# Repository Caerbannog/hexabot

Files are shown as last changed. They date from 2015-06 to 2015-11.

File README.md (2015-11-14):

Hexabot Sources
===============

Design files and source code of a mobile robot for the [Eurobot competition](http://www.eurobot.org/).

The controller board is built in [KiCad](http://www.kicad-pcb.org/)
around a [dsPIC33EP256MU806](https://www.microchip.com/products/dsPIC33EP256MU806) (QFN, motor control, USB).
You can control it from your development machine or an embedded Linux like the Raspberry Pi (raspbian jessie recommended).

Controller PCB
--------------
The board handles various functions: motor control, odometry, sensors and servomotors.
It has two layers, 10cm*10cm and mostly 0806 SMT components.

You can buy 10 PCBs for 32$ at [SeeedStudio](http://www.seeedstudio.com/service/index.php?r=pcb).
Then we hand-soldered ours.

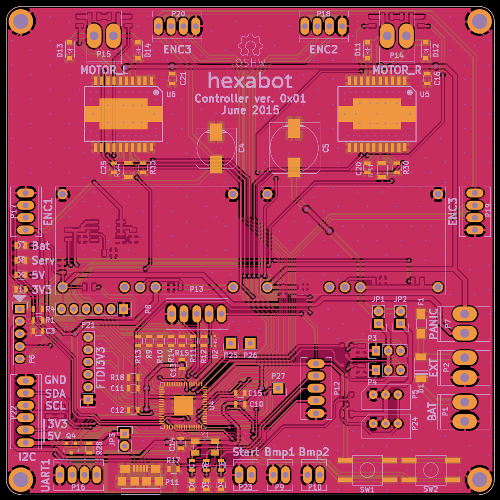
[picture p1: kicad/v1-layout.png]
Layout v1


Embedded Software
-----------------
The source code for the microcontroller is in [hexabot-dsPIC33.X](hexabot-dsPIC33.X/).
It is controlled with the tools in [linux](linux/). Most are Python scripts that
use [PyUSB](https://walac.github.io/pyusb/) to communicate with the board through independant USB endpoints:
- Bulk commands to set parameters and read back values. The basic idea is to run `./command.py <register> <value>` to set a value.
- Bulk metrics broadcasting, isochronous packets for time-sensitive data. Dump them with `./usb_controller.py`.
- Serial port for debugging. Show the debug console with `miniterm.py /dev/ttyACM* 9600 -D`.

A higher level scripts like `joystick.py` uses the command endpoint to let you control the motors with a USB joystick.

User Interface
--------------
The [ui](ui/) directory contains a Python webserver with these features:
- live updates of the position according to odometry,
- graphs to visualize metrics,
- maybe someday a way to send commands.

Setup
-----
Download and install the [MPLABX IDE](http://www.microchip.com/mplabx/) and the [XC16 compiler](http://www.microchip.com/compilers/).
You need xc16 v1.25+ because of bug XC16-781 (snprintf).
Sadly the peripheral libraries were last shipped with v1.24 and the new Code Configurator doesn't support dsPIC33E yet.
You need to copy the libraries from one installed version to the other.

Install Python 3 and debugging tools like Wireshark.
For Ubuntu 15.04 you can run:
```bash
git clone https://github.com/Caerbannog/hexabot.git
sudo apt-get install python3-pip wireshark
sudo pip3 install pyusb==1.0.0b1 autobahn==0.10.4 pyinotify==0.9.6 bottle==0.12.8 pyserial
sudo adduser $USER dialout
sudo adduser $USER wireshark
echo usbmon | sudo tee -a /etc/modules
sudo cp 99-hexabot.rules /etc/udev/rules.d/
sudo service udev reload # then you need to replug the device
```

Contributing
------------
Pull requests are welcome on the project page:
<https://github.com/Caerbannog/hexabot>

Licenses
--------
- Hardware design files are published under the CERN OHL v.1.2.
- Source code is published under the GPLv3 or later.
- Note that Microchip's USB library and the CDC-basic demo have a more restrictive license.

TODO list
---------
- Documentation for the code. Links to documentation for the motor control and odometry.

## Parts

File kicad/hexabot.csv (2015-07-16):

Reference | Value | Footprint | Datasheet
U4 | DSPIC33EP256MU806 | hexabot:QFN-64-1EP_9x9mm_Pitch0.5mm
D4 | LEDR | Resistors_SMD:R_0805
D5 | LEDY | Resistors_SMD:R_0805
D6 | LEDG | Resistors_SMD:R_0805
R19 | 470R | Resistors_SMD:R_0805
R20 | 470R | Resistors_SMD:R_0805
R21 | 470R | Resistors_SMD:R_0805
Y1 | 8M | hexabot:XTAL_5x3.2 | http://www.abracon.com/Resonators/abm3b.pdf
R8 | 1M | Resistors_SMD:R_0805
C7 | 18p | Resistors_SMD:R_0805
C8 | 18p | Resistors_SMD:R_0805
P6 | PICKIT | Pin_Headers:Pin_Header_Straight_1x05
P11 | USB_B | hexabot:MICRO-B_USB
JP3 | JUMPER | Pin_Headers:Pin_Header_Straight_1x02
LOGO1 | OPEN_HARDWARE_1 | Symbols:Symbol_OSHW-Logo_SilkScreen
P13 | NC | Sockets_MOLEX_KK-System:Socket_MOLEX-KK-RM2-54mm_Lock_5pin_straight
C12 | 100n | Resistors_SMD:R_0805
C13 | 100n | Resistors_SMD:R_0805
C14 | 100n | Resistors_SMD:R_0805
C15 | 100n | Resistors_SMD:R_0805
R4 | 330R | Resistors_SMD:R_0805
R1 | 4K7 | Resistors_SMD:R_0805
C3 | 100n | Resistors_SMD:R_0805
C10 | 10u | Resistors_SMD:R_0805
R18 | 0R | Resistors_SMD:R_0805
C11 | 100n | Resistors_SMD:R_0805
P3 | SERVO1 | Pin_Headers:Pin_Header_Straight_1x03
Q1 | Q_NMOS_GSD | Housings_SOT-23_SOT-143_TSOT-6:SOT-23
R17 | 0R | Resistors_SMD:R_0805
P8 | NC | Pin_Headers:Pin_Header_Straight_1x06
P20 | ENC4 | Sockets_MOLEX_KK-System:Socket_MOLEX-KK-RM2-54mm_Lock_4pin_straight
P19 | ENC3 | Sockets_MOLEX_KK-System:Socket_MOLEX-KK-RM2-54mm_Lock_4pin_straight
P18 | ENC2 | Sockets_MOLEX_KK-System:Socket_MOLEX-KK-RM2-54mm_Lock_4pin_straight
P17 | ENC1 | Sockets_MOLEX_KK-System:Socket_MOLEX-KK-RM2-54mm_Lock_4pin_straight
P16 | UART1_5V | Sockets_MOLEX_KK-System:Socket_MOLEX-KK-RM2-54mm_Lock_4pin_straight
P21 | UART2_FTDI3V3 | Pin_Headers:Pin_Header_Straight_1x06
Q4 | Q_NMOS_GSD | Housings_SOT-23_SOT-143_TSOT-6:SOT-23
R28 | 1k | Resistors_SMD:R_0805
JP1 | JUMPER | Pin_Headers:Pin_Header_Straight_1x02
MH3 | HOLE_M3 | hexabot:M3-hole-plated
MH2 | HOLE_M3 | hexabot:M3-hole-plated
MH4 | HOLE_M3 | hexabot:M3-hole-plated
MH1 | HOLE_M3 | hexabot:M3-hole-plated
SW1 | PUSH1 | hexabot:SW_PUSH-SMD
SW2 | PUSH2 | hexabot:SW_PUSH-SMD
P12 | DEBUG | Sockets_MOLEX_KK-System:Socket_MOLEX-KK-RM2-54mm_Lock_5pin_straight
P1 | BATTERY | Sockets_MOLEX_KK-System:Socket_MOLEX-KK-RM3-96mm_Lock_2pin_straight
R2 | 21k | Resistors_SMD:R_0805
U1 | PTN78020 +5V | hexabot:PTN78020H
C1 | 2u2 | Resistors_SMD:R_0805
C4 | 330u | hexabot:c_elec_8x10.5
R3 | 7k52 | Resistors_SMD:R_0805
U3 | MCP1727 | hexabot:SOIC-8_3.9x4.9mm_Pitch1.27mm
U2 | PTN78020 SERVO | hexabot:PTN78020H
C2 | 2u2 | Resistors_SMD:R_0805
C5 | 330u | hexabot:c_elec_10x10.5
C6 | 4u7 | Resistors_SMD:R_0805
C9 | 4u7 | Resistors_SMD:R_0805
R5 | 10k | Resistors_SMD:R_0805
P4 | SERVO2 | Pin_Headers:Pin_Header_Straight_1x03
Q2 | Q_NMOS_GSD | Housings_SOT-23_SOT-143_TSOT-6:SOT-23
R6 | 10k | Resistors_SMD:R_0805
P5 | DYNAMIXEL1 | hexabot:molex-22-03-5035
Q3 | Q_NMOS_GSD | Housings_SOT-23_SOT-143_TSOT-6:SOT-23
P14 | MOTOR_R | Sockets_MOLEX_KK-System:Socket_MOLEX-KK-RM3-96mm_Lock_2pin_straight
P15 | MOTOR_L | Sockets_MOLEX_KK-System:Socket_MOLEX-KK-RM3-96mm_Lock_2pin_straight
R27 | 10k | Resistors_SMD:R_0805
R26 | 10k | Resistors_SMD:R_0805
P22 | NC | Sockets_MOLEX_KK-System:Socket_MOLEX-KK-RM2-54mm_Lock_6pin_straight
D7 | LEDB | Resistors_SMD:R_0805
R22 | 10k | Resistors_SMD:R_0805
D8 | LEDB | Resistors_SMD:R_0805
R23 | 2k | Resistors_SMD:R_0805
D10 | LEDB | Resistors_SMD:R_0805
R25 | 470R | Resistors_SMD:R_0805
D9 | LEDB | Resistors_SMD:R_0805
R24 | 1k | Resistors_SMD:R_0805
P7 | PANIC BUTTON | Sockets_MOLEX_KK-System:Socket_MOLEX-KK-RM3-96mm_Lock_2pin_straight
D1 | D | hexabot:SOD-128
P2 | EXT_POWER | Sockets_MOLEX_KK-System:Socket_MOLEX-KK-RM3-96mm_Lock_2pin_straight
JP2 | JUMPER | Pin_Headers:Pin_Header_Straight_1x02
R7 | 10k | Resistors_SMD:R_0805
F1 | FUSE | Resistors_SMD:R_1206_HandSoldering
R13 | NC | Resistors_SMD:R_0805
R14 | NC | Resistors_SMD:R_0805
R15 | NC | Resistors_SMD:R_0805
R16 | 1k | Resistors_SMD:R_0805
R12 | 9k | Resistors_SMD:R_0805
R11 | NC | Resistors_SMD:R_0805
R10 | NC | Resistors_SMD:R_0805
R9 | NC | Resistors_SMD:R_0805
P9 | BUMP1 | Sockets_MOLEX_KK-System:Socket_MOLEX-KK-RM2-54mm_Lock_2pin_straight
P10 | BUMP2 | Sockets_MOLEX_KK-System:Socket_MOLEX-KK-RM2-54mm_Lock_2pin_straight
C26 | NC | Resistors_SMD:R_0805
P23 | START | Sockets_MOLEX_KK-System:Socket_MOLEX-KK-RM2-54mm_Lock_2pin_straight
R35 | 1k | Resistors_SMD:R_0805
D3 | ZENER | Diodes_SMD:SOD-323
P24 | DYNAMIXEL2 | hexabot:molex-22-03-5035
D2 | ZENER | Diodes_SMD:SOD-323
P25 | NC | Pin_Headers:Pin_Header_Straight_1x01
P26 | NC | Pin_Headers:Pin_Header_Straight_1x01
P27 | NC | Pin_Headers:Pin_Header_Straight_1x01
U5 | L6201PS | hexabot:powerso-20
C16 | 100n | Resistors_SMD:R_0805
C17 | 15n | Resistors_SMD:R_0805
C19 | 15n | Resistors_SMD:R_0805
R31 | 0R1 3W | Resistors_SMD:R_1206
C18 | 22n | Resistors_SMD:R_0805
R29 | 10R | Resistors_SMD:R_0805
D11 | D | Diodes_SMD:SOD-123
D12 | D | Diodes_SMD:SOD-123
C20 | 220n | Resistors_SMD:R_0805
R30 | 10k | Resistors_SMD:R_0805
U6 | L6201PS | hexabot:powerso-20
C21 | 100n | Resistors_SMD:R_0805
C22 | 15n | Resistors_SMD:R_0805
C24 | 15n | Resistors_SMD:R_0805
R34 | 0R1 3W | Resistors_SMD:R_1206
C23 | 22n | Resistors_SMD:R_0805
R32 | 10R | Resistors_SMD:R_0805
D13 | D | Diodes_SMD:SOD-123
D14 | D | Diodes_SMD:SOD-123
C25 | 220n | Resistors_SMD:R_0805
R33 | 10k | Resistors_SMD:R_0805

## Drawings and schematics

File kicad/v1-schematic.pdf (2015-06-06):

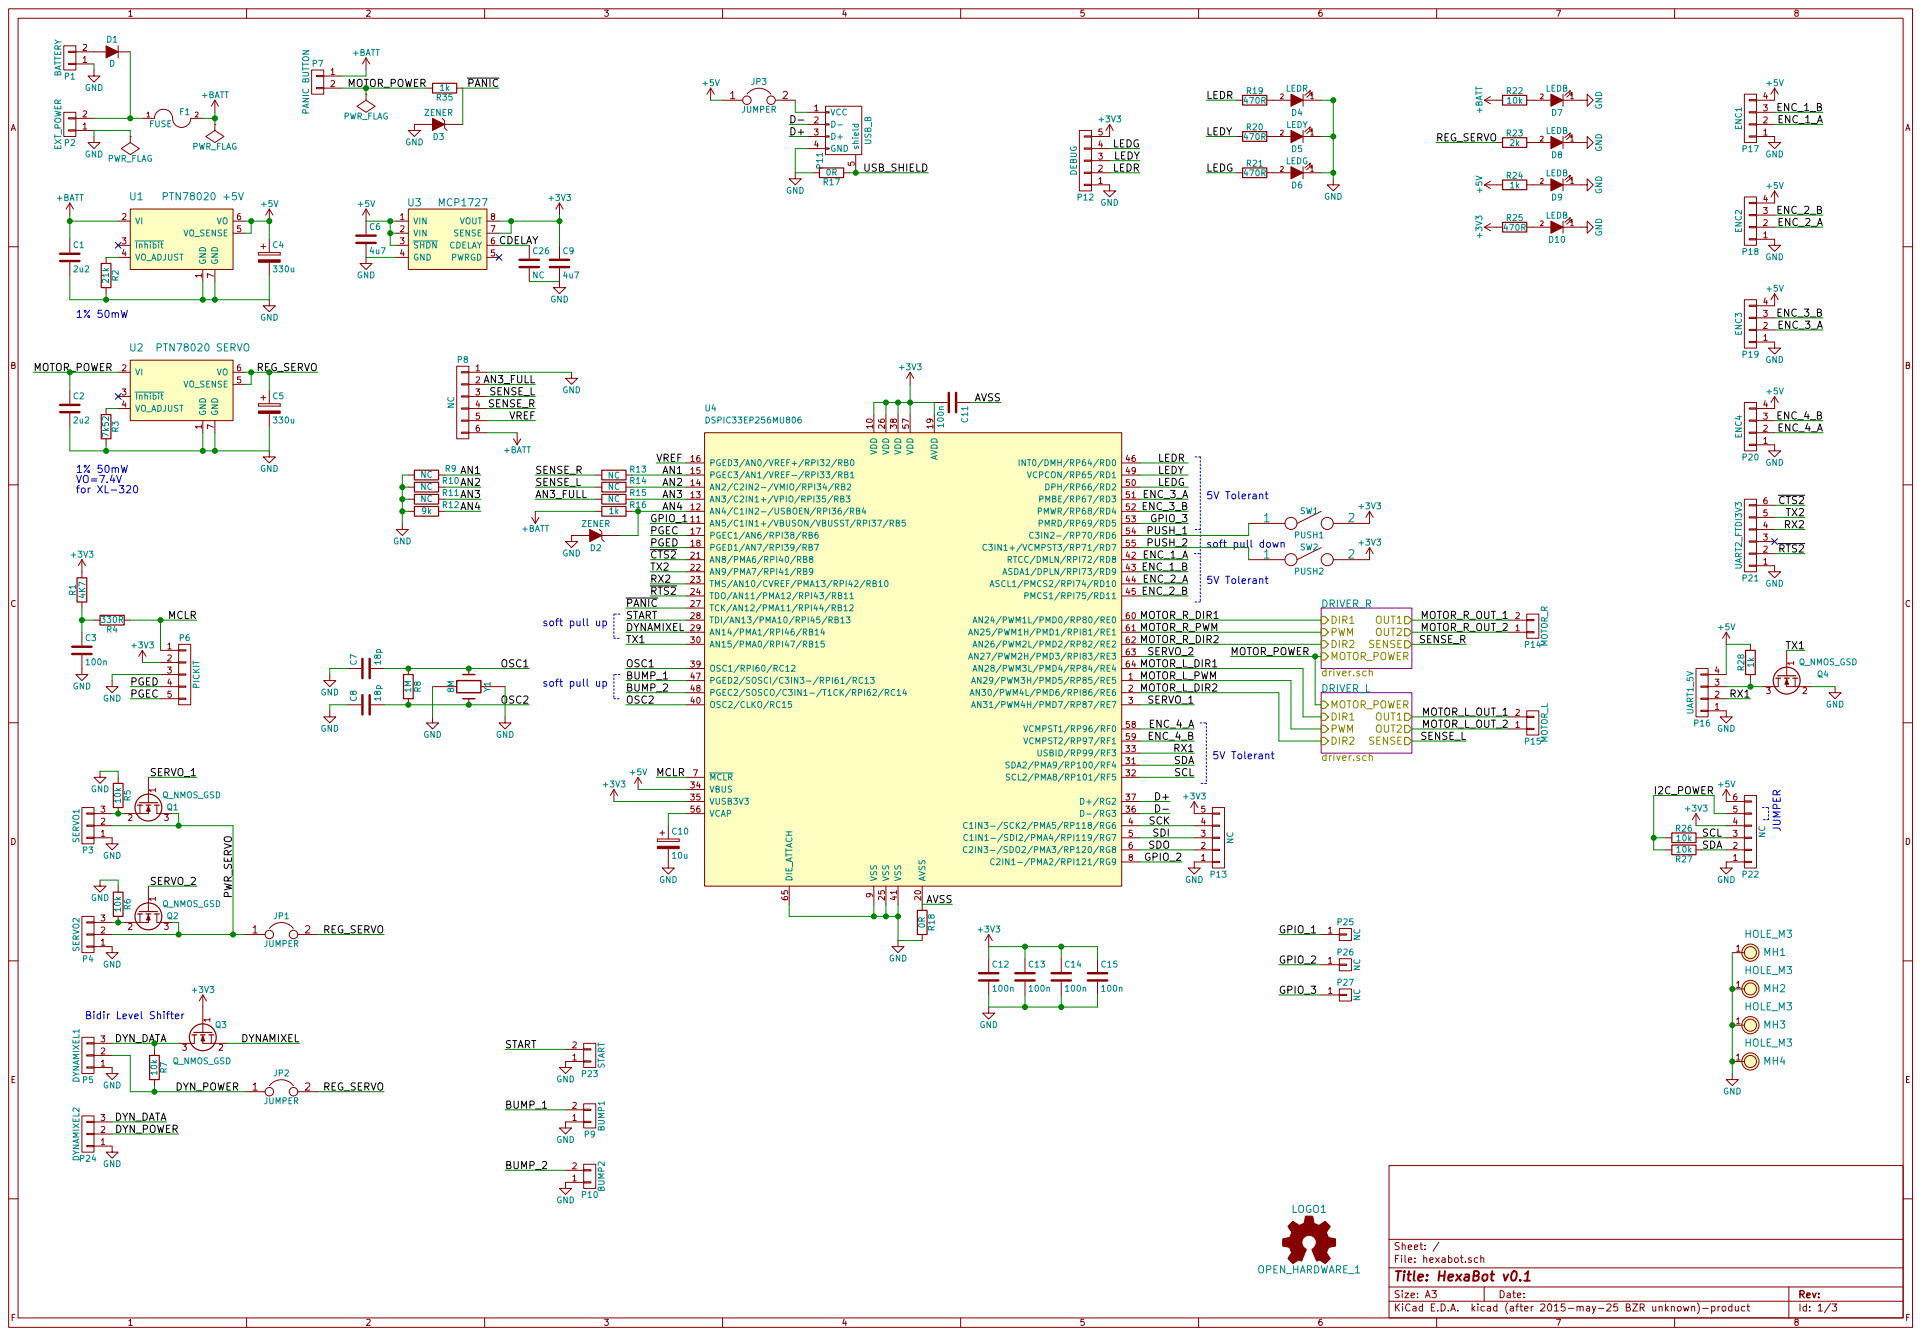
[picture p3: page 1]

9 VDD 10 AVSS 20 AN15/PMA0/RPI47/RB15 30 OSC2/CLKO/RC15 40 DPH/RP66/RD2 50 AN24/PWM1L/PMD0/RP80/RE0 60 AN5/C1IN1+/VBUSON/VBUSST/RPI37/RB5 11 AN8/PMA6/RPI40/RB8 21 SDA2/PMA9/RP100/RF4 31 VSS 41 PMBE/RP67/RD3 51 AN25/PWM1H/PMD1/RPI81/RE1 61 AN4/C1IN2-/USBOEN/RPI36/RB4 12 AN9/PMA7/RPI41/RB9 22 SCL2/PMA8/RP101/RF5 32 RTCC/DMLN/RPI72/RD8 42 PMWR/RP68/RD4 52 AN26/PWM2L/PMD2/RP82/RE2 62 AN3/C2IN1+/VPIO/RPI35/RB3 13 TMS/AN10/CVREF/PMA13/RPI42/RB10 23 USBID/RP99/RF3 33 ASDA1/DPLN/RPI73/RD9 43 PMRD/RP69/RD5 53 AN27/PWM2H/PMD3/RPI83/RE3 63 AN2/C2IN2-/VMIO/RPI34/RB2 14 TDO/AN11/PMA12/RPI43/RB11 24 VBUS 34 ASCL1/PMCS2/RPI74/RD10 44 C3IN2-/RP70/RD6 54 AN28/PWM3L/PMD4/RP84/RE4 64 PGEC3/AN1/VREF-/RPI33/RB1 15 VSS 25 VUSB3V3 35 PMCS1/RPI75/RD11 45 C3IN1+/VCMPST3/RP71/RD7 55 DIE_ATTACH 65 PGED3/AN0/VREF+/RPI32/RB0 16 VDD 26 D-/RG3 36

GPIO_1 | GPIO_3

PUSH_2
ENC_1_A

MOTOR_R_DIR2
SERVO_2
MOTOR_L_DIR1
MOTOR_L_PWM

File: hexabot.sch Sheet: /
Id: 1/3 Title: HexaBot v0.1

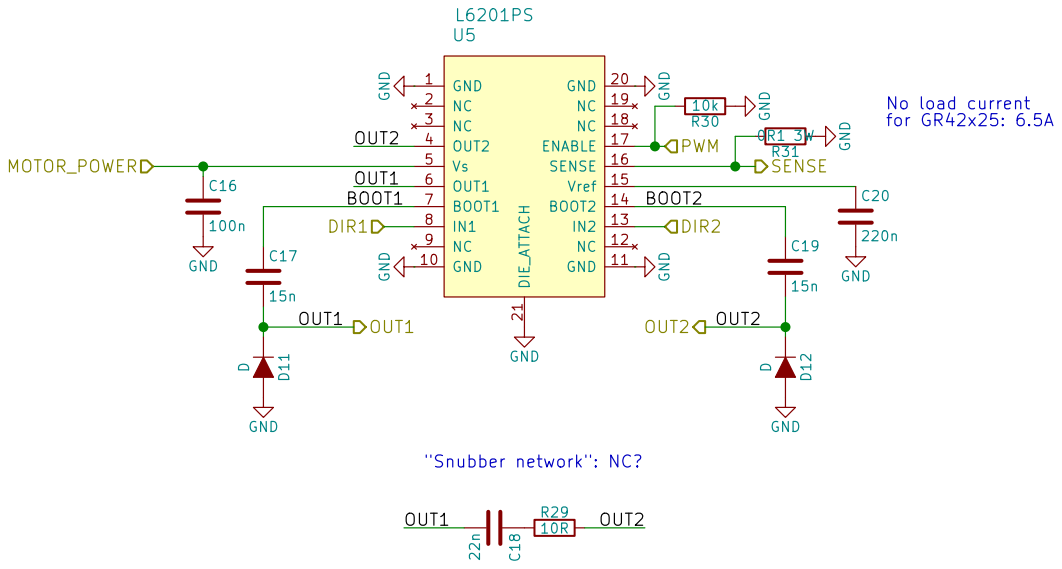
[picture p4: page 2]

Id: 2/3 Title: File: driver.sch Sheet: /DRIVER_R/

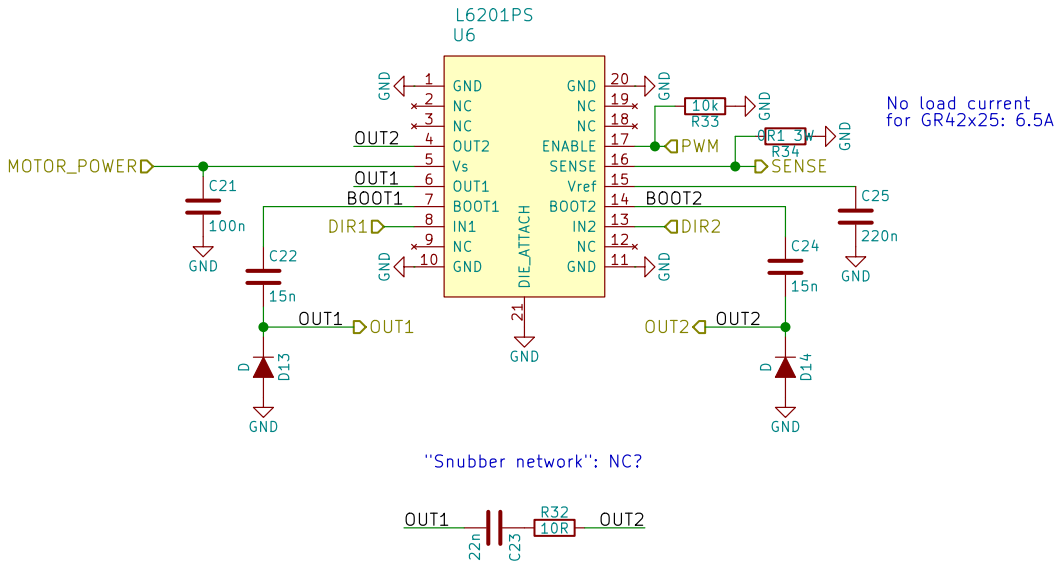
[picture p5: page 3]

Id: 3/3 Title: File: driver.sch Sheet: /DRIVER_L/

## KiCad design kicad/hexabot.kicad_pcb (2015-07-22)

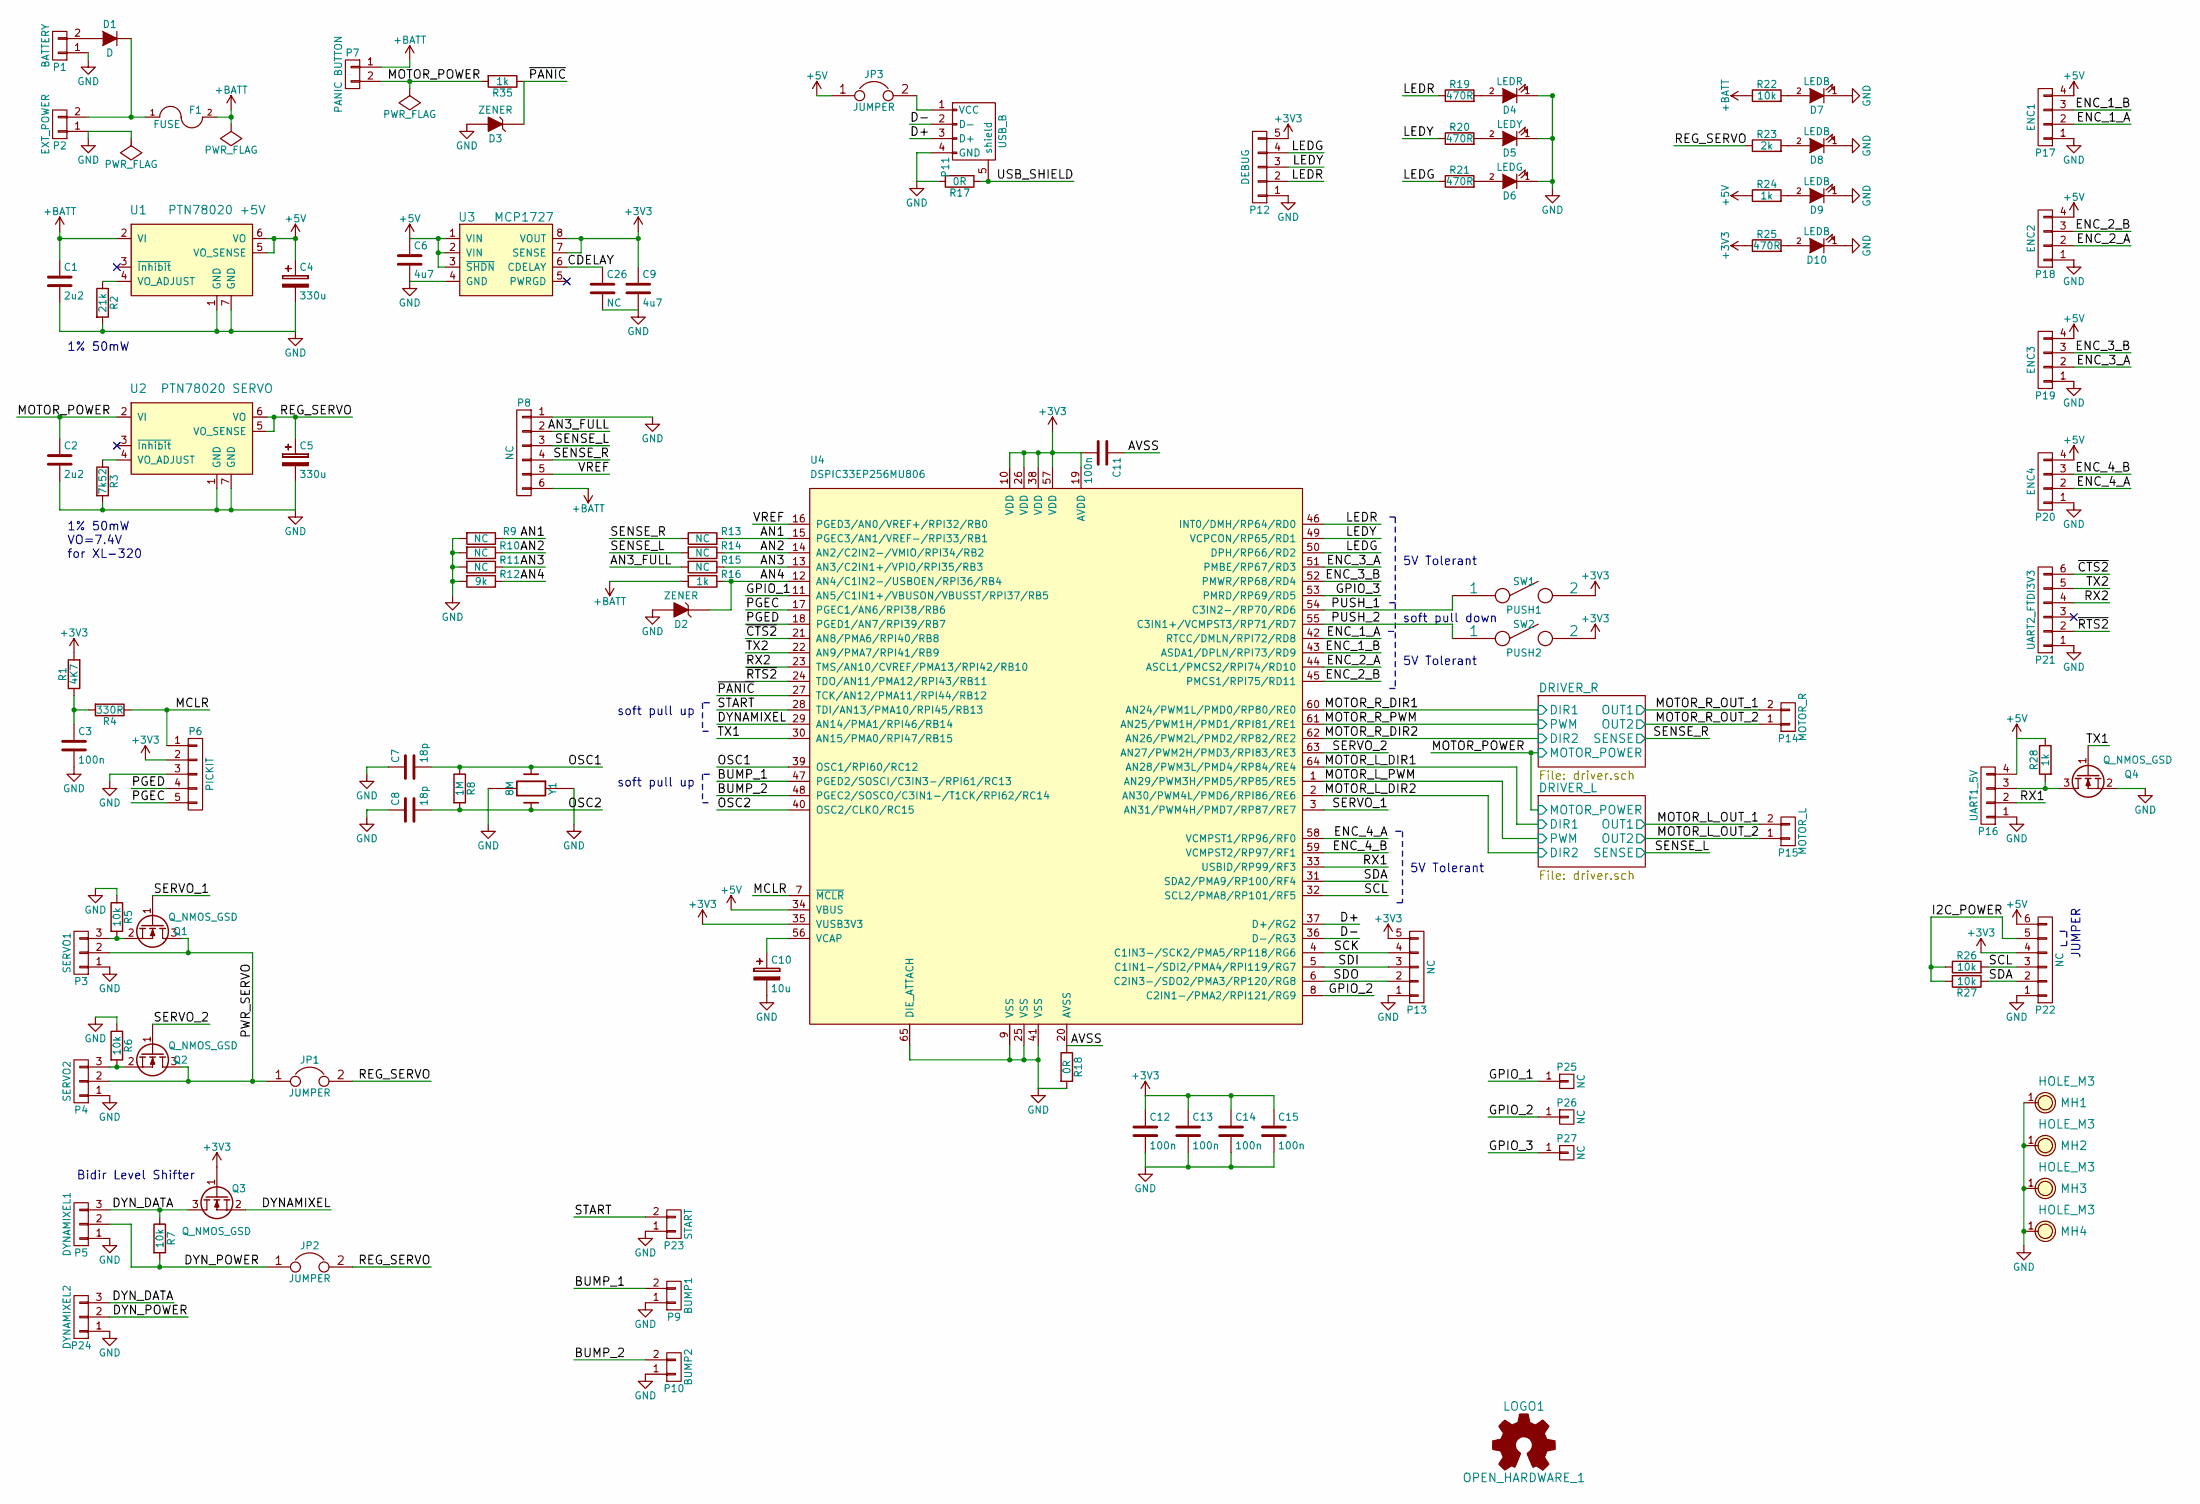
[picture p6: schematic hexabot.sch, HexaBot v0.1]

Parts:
C1, C2: 2u2; R_0805
C3, C11, C12, C13, C14, C15: 100n; R_0805
C4: 330u; c_elec_8x10.5
C5: 330u; c_elec_10x10.5
C6, C9: 4u7; R_0805
C7, C8: 18p; R_0805
C10: 10u; R_0805
C26: NC; R_0805
D1: D; SOD-128
D2, D3: ZENER; SOD-323
D4: LEDR; R_0805
D5: LEDY; R_0805
D6: LEDG; R_0805
D7, D8, D9, D10: LEDB; R_0805
F1: FUSE; R_1206_HandSoldering
JP1, JP2, JP3: JUMPER; Pin_Header_Straight_1x02
LOGO1: OPEN_HARDWARE_1; Symbol_OSHW-Logo_SilkScreen
MH1, MH2, MH3, MH4: HOLE_M3; M3-hole-plated
P1: BATTERY; Socket_MOLEX-KK-RM3-96mm_Lock_2pin_straight
P2: EXT_POWER; Socket_MOLEX-KK-RM3-96mm_Lock_2pin_straight
P3: SERVO1; Pin_Header_Straight_1x03
P4: SERVO2; Pin_Header_Straight_1x03
P5: DYNAMIXEL1; molex-22-03-5035
P6: PICKIT; Pin_Header_Straight_1x05
P7: PANIC BUTTON; Socket_MOLEX-KK-RM3-96mm_Lock_2pin_straight
P8: NC; Pin_Header_Straight_1x06
P9: BUMP1; Socket_MOLEX-KK-RM2-54mm_Lock_2pin_straight
P10: BUMP2; Socket_MOLEX-KK-RM2-54mm_Lock_2pin_straight
P11: USB_B; MICRO-B_USB
P12: DEBUG; Socket_MOLEX-KK-RM2-54mm_Lock_5pin_straight
P13: NC; Socket_MOLEX-KK-RM2-54mm_Lock_5pin_straight
P14: MOTOR_R; Socket_MOLEX-KK-RM3-96mm_Lock_2pin_straight
P15: MOTOR_L; Socket_MOLEX-KK-RM3-96mm_Lock_2pin_straight
P16: UART1_5V; Socket_MOLEX-KK-RM2-54mm_Lock_4pin_straight
P17: ENC1; Socket_MOLEX-KK-RM2-54mm_Lock_4pin_straight
P18: ENC2; Socket_MOLEX-KK-RM2-54mm_Lock_4pin_straight
P19: ENC3; Socket_MOLEX-KK-RM2-54mm_Lock_4pin_straight
P20: ENC4; Socket_MOLEX-KK-RM2-54mm_Lock_4pin_straight
P21: UART2_FTDI3V3; Pin_Header_Straight_1x06
P22: NC; Socket_MOLEX-KK-RM2-54mm_Lock_6pin_straight
P23: START; Socket_MOLEX-KK-RM2-54mm_Lock_2pin_straight
P24: DYNAMIXEL2; molex-22-03-5035
P25, P26, P27: NC; Pin_Header_Straight_1x01
Q1, Q2, Q3, Q4: Q_NMOS_GSD; SOT-23
R1: 4K7; R_0805
R2: 21k; R_0805
R3: 7k52; R_0805
R4: 330R; R_0805
R5, R6, R7, R22, R26, R27: 10k; R_0805
R8: 1M; R_0805
R9, R10, R11, R13, R14, R15: NC; R_0805
R12: 9k; R_0805
R16, R24, R28, R35: 1k; R_0805
R17, R18: 0R; R_0805
R19, R20, R21, R25: 470R; R_0805
R23: 2k; R_0805
SW1: PUSH1; SW_PUSH-SMD
SW2: PUSH2; SW_PUSH-SMD
U1: PTN78020 +5V; PTN78020H
U2: PTN78020 SERVO; PTN78020H
U3: MCP1727; SOIC-8_3.9x4.9mm_Pitch1.27mm
U4: DSPIC33EP256MU806; QFN-64-1EP_9x9mm_Pitch0.5mm
Y1: 8M; XTAL_5x3.2

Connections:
+3V3: C9.1, C11.2, C12.1, C13.1, C14.1, C15.1, P6.2, P12.5, P13.5, P22.4, Q3.1 (G), R1.2, R25.1, SW1.2, SW2.2, U3.7 (SENSE), U3.8 (VOUT), U4.10 (VDD), U4.19 (AVDD), U4.26 (VDD), U4.35 (VUSB3V3), U4.38 (VDD), U4.57 (VDD)
+5V: C4.1, C6.1, JP3.1, P16.4, P17.4, P18.4, P19.4, P20.4, P22.6, R24.1, R28.1, U1.5 (VO_SENSE), U1.6 (VO), U3.1 (VIN), U3.2 (VIN), U3.3 (~SHDN), U4.34 (VBUS)
+BATT: C1.1, F1.2, P7.1, P8.6, R16.2, R22.1, U1.2 (VI)
/AN1: R9.1, R13.2, U4.15 (PGEC3/AN1/VREF-/RPI33/RB1)
/AN2: R10.1, R14.1, U4.14 (AN2/C2IN2-/VMIO/RPI34/RB2)
/AN3: R11.1, R15.1, U4.13 (AN3/C2IN1+/VPIO/RPI35/RB3)
/AN3_FULL: P8.2, R15.2
/AN4: D2.1 (K), R12.1, R16.1, U4.12 (AN4/C1IN2-/USBOEN/RPI36/RB4)
/AVSS: C11.1, R18.1, U4.20 (AVSS)
/BUMP_1: P9.2, U4.47 (PGED2/SOSCI/C3IN3-/RPI61/RC13)
/BUMP_2: P10.2, U4.48 (PGEC2/SOSCO/C3IN1-/T1CK/RPI62/RC14)
/CDELAY: C26.1, U3.6 (CDELAY)
/D+: P11.3 (D+), U4.37 (D+/RG2)
/D-: P11.2 (D-), U4.36 (D-/RG3)
/DRIVER_L/DIR1: U4.64 (AN28/PWM3L/PMD4/RP84/RE4); also elsewhere on the board
/DRIVER_L/DIR2: U4.2 (AN30/PWM4L/PMD6/RPI86/RE6); also elsewhere on the board
/DRIVER_L/MOTOR_POWER: C2.1, P7.2, R35.2, U2.2 (VI); also elsewhere on the board
/DRIVER_L/OUT1: P15.2; also elsewhere on the board
/DRIVER_L/OUT2: P15.1; also elsewhere on the board
/DRIVER_L/PWM: U4.1 (AN29/PWM3H/PMD5/RP85/RE5); also elsewhere on the board
/DRIVER_L/SENSE: P8.3, R14.2; also elsewhere on the board
/DRIVER_R/DIR1: U4.60 (AN24/PWM1L/PMD0/RP80/RE0); also elsewhere on the board
/DRIVER_R/DIR2: U4.62 (AN26/PWM2L/PMD2/RP82/RE2); also elsewhere on the board
/DRIVER_R/OUT1: P14.2; also elsewhere on the board
/DRIVER_R/OUT2: P14.1; also elsewhere on the board
/DRIVER_R/PWM: U4.61 (AN25/PWM1H/PMD1/RPI81/RE1); also elsewhere on the board
/DRIVER_R/SENSE: P8.4, R13.1; also elsewhere on the board
/DYNAMIXEL: Q3.2 (S), U4.29 (AN14/PMA1/RPI46/RB14)
/DYN_DATA: P5.3, P24.3, Q3.3 (D), R7.1
/DYN_POWER: JP2.1, P5.2, P24.2, R7.2
/ENC_1_A: P17.2, U4.42 (RTCC/DMLN/RPI72/RD8)
/ENC_1_B: P17.3, U4.43 (ASDA1/DPLN/RPI73/RD9)
/ENC_2_A: P18.2, U4.44 (ASCL1/PMCS2/RPI74/RD10)
/ENC_2_B: P18.3, U4.45 (PMCS1/RPI75/RD11)
/ENC_3_A: P19.2, U4.51 (PMBE/RP67/RD3)
/ENC_3_B: P19.3, U4.52 (PMWR/RP68/RD4)
/ENC_4_A: P20.2, U4.58 (VCMPST1/RP96/RF0)
/ENC_4_B: P20.3, U4.59 (VCMPST2/RP97/RF1)
/GPIO_1: P25.1, U4.11 (AN5/C1IN1+/VBUSON/VBUSST/RPI37/RB5)
/GPIO_2: P26.1, U4.8 (C2IN1-/PMA2/RPI121/RG9)
/GPIO_3: P27.1, U4.53 (PMRD/RP69/RD5)
/I2C_POWER: P22.5, R26.1, R27.2
/LEDG: P12.4, R21.1, U4.50 (DPH/RP66/RD2)
/LEDR: P12.2, R19.1, U4.46 (INT0/DMH/RP64/RD0)
/LEDY: P12.3, R20.1, U4.49 (VCPCON/RP65/RD1)
/MCLR: P6.1, R4.1, U4.7 (~MCLR)
/OSC1: C7.2, R8.1, U4.39 (OSC1/RPI60/RC12), Y1.1
/OSC2: C8.2, R8.2, U4.40 (OSC2/CLKO/RC15), Y1.2
/PGEC: P6.5, U4.17 (PGEC1/AN6/RPI38/RB6)
/PGED: P6.4, U4.18 (PGED1/AN7/RPI39/RB7)
/PUSH_1: SW1.1, U4.54 (C3IN2-/RP70/RD6)
/PUSH_2: SW2.1, U4.55 (C3IN1+/VCMPST3/RP71/RD7)
/PWR_SERVO: JP1.1, P3.2, P4.2, Q1.3 (D), Q2.3 (D)
/REG_SERVO: C5.1, JP1.2, JP2.2, R23.1, U2.5 (VO_SENSE), U2.6 (VO)
/RX1: P16.2, U4.33 (USBID/RP99/RF3)
/RX2: P21.4, U4.23 (TMS/AN10/CVREF/PMA13/RPI42/RB10)
/SCK: P13.4, U4.4 (C1IN3-/SCK2/PMA5/RP118/RG6)
/SCL: P22.3, R26.2, U4.32 (SCL2/PMA8/RP101/RF5)
/SDA: P22.2, R27.1, U4.31 (SDA2/PMA9/RP100/RF4)
/SDI: P13.3, U4.5 (C1IN1-/SDI2/PMA4/RPI119/RG7)
/SDO: P13.2, U4.6 (C2IN3-/SDO2/PMA3/RP120/RG8)
/SERVO_1: Q1.1 (G), U4.3 (AN31/PWM4H/PMD7/RP87/RE7)
/SERVO_2: Q2.1 (G), U4.63 (AN27/PWM2H/PMD3/RPI83/RE3)
/START: P23.2, U4.28 (TDI/AN13/PMA10/RPI45/RB13)
/TX1: Q4.1 (G), U4.30 (AN15/PMA0/RPI47/RB15)
/TX2: P21.5, U4.22 (AN9/PMA7/RPI41/RB9)
/USB_SHIELD: P11.5 (shield), R17.1
/VREF: P8.5, U4.16 (PGED3/AN0/VREF+/RPI32/RB0)
/~CTS2: P21.6, U4.21 (AN8/PMA6/RPI40/RB8)
/~PANIC: D3.1 (K), R35.1, U4.27 (TCK/AN12/PMA11/RPI44/RB12)
/~RTS2: P21.2, U4.24 (TDO/AN11/PMA12/RPI43/RB11)
GND: C1.2, C2.2, C3.2, C4.2, C5.2, C6.2, C7.1, C8.1, C9.2, C10.2, C12.2, C13.2, C14.2, C15.2, C26.2, D2.2 (A), D3.2 (A), D4.1 (K), D5.1 (K), D6.1 (K), D7.1 (K), D8.1 (K), D9.1 (K), D10.1 (K), MH1.1, MH2.1, MH3.1, MH4.1, P1.1, P2.1, P3.1, P4.1, P5.1, P6.3, P8.1, P9.1, P10.1, P11.4 (GND), P12.1, P13.1, P16.1, P17.1, P18.1, P19.1, P20.1, P21.1, P22.1, P23.1, P24.1, Q4.2 (S), R2.2, R3.2, R5.1, R6.1, R9.2, R10.2, R11.2, R12.2, R17.2, R18.2, U1.1 (GND), U1.7 (GND), U2.1 (GND), U2.7 (GND), U3.4 (GND), U4.9 (VSS), U4.25 (VSS), U4.41 (VSS), U4.65 (DIE_ATTACH), Y1.3 (GND), Y1.4 (GND); also elsewhere on the board
unnamed: C3.1, R1.1, R4.2
unnamed: C10.1, U4.56 (VCAP)
unnamed: D1.1 (K), F1.1, P2.2
unnamed: D1.2 (A), P1.2
unnamed: D4.2 (A), R19.2
unnamed: D5.2 (A), R20.2
unnamed: D6.2 (A), R21.2
unnamed: D7.2 (A), R22.2
unnamed: D8.2 (A), R23.2
unnamed: D9.2 (A), R24.2
unnamed: D10.2 (A), R25.2
unnamed: JP3.2, P11.1 (VCC)
unnamed: P3.3, Q1.2 (S), R5.2
unnamed: P4.3, Q2.2 (S), R6.2
unnamed: P16.3, Q4.3 (D), R28.2
unnamed: R2.1, U1.4 (VO_ADJUST)
unnamed: R3.1, U2.4 (VO_ADJUST)

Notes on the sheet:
5V Tolerant
1% 50mW
1% 50mW VO=7.4V for XL-320
soft pull down
JUMPER
soft pull up
Bidir Level Shifter

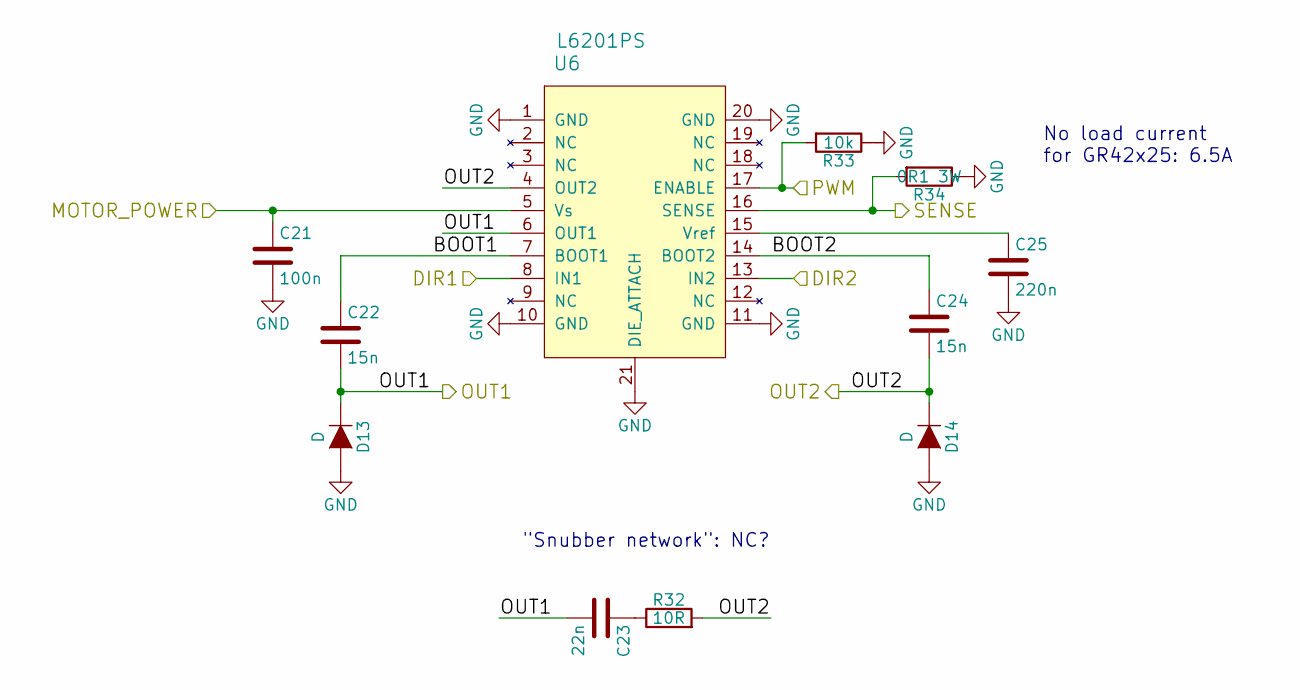
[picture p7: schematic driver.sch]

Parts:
C16: 100n; R_0805
C17, C19: 15n; R_0805
C18: 22n; R_0805
C20: 220n; R_0805
D11, D12: D; SOD-123
R29: 10R; R_0805
R30: 10k; R_0805
R31: 0R1 3W; R_1206
U5: L6201PS; powerso-20

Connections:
/DRIVER_L/MOTOR_POWER: C16.1, U5.5 (Vs); also elsewhere on the board
/DRIVER_R/BOOT1: C17.1, U5.7 (BOOT1)
/DRIVER_R/BOOT2: C19.1, U5.14 (BOOT2)
/DRIVER_R/DIR1: U5.8 (IN1); also elsewhere on the board
/DRIVER_R/DIR2: U5.13 (IN2); also elsewhere on the board
/DRIVER_R/OUT1: C17.2, C18.2, D11.1 (K), U5.6 (OUT1); also elsewhere on the board
/DRIVER_R/OUT2: C19.2, D12.1 (K), R29.2, U5.4 (OUT2); also elsewhere on the board
/DRIVER_R/PWM: R30.2, U5.17 (ENABLE); also elsewhere on the board
/DRIVER_R/SENSE: R31.2, U5.16 (SENSE); also elsewhere on the board
GND: C16.2, C20.2, D11.2 (A), D12.2 (A), R30.1, R31.1, U5.1 (GND), U5.10 (GND), U5.11 (GND), U5.20 (GND), U5.21 (DIE_ATTACH); also elsewhere on the board
unnamed: C18.1, R29.1
unnamed: C20.1, U5.15 (Vref)

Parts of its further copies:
C21: 100n; R_0805
C22, C24: 15n; R_0805
C23: 22n; R_0805
C25: 220n; R_0805
D13, D14: D; SOD-123
R32: 10R; R_0805
R33: 10k; R_0805
R34: 0R1 3W; R_1206
U6: L6201PS; powerso-20

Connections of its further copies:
/DRIVER_L/BOOT1: C22.1, U6.7 (BOOT1)
/DRIVER_L/BOOT2: C24.1, U6.14 (BOOT2)
/DRIVER_L/DIR1: U6.8 (IN1); also elsewhere on the board
/DRIVER_L/DIR2: U6.13 (IN2); also elsewhere on the board
/DRIVER_L/MOTOR_POWER: C21.1, U6.5 (Vs); also elsewhere on the board
/DRIVER_L/OUT1: C22.2, C23.2, D13.1 (K), U6.6 (OUT1); also elsewhere on the board
/DRIVER_L/OUT2: C24.2, D14.1 (K), R32.2, U6.4 (OUT2); also elsewhere on the board
/DRIVER_L/PWM: R33.2, U6.17 (ENABLE); also elsewhere on the board
/DRIVER_L/SENSE: R34.2, U6.16 (SENSE); also elsewhere on the board
GND: C21.2, C25.2, D13.2 (A), D14.2 (A), R33.1, R34.1, U6.1 (GND), U6.10 (GND), U6.11 (GND), U6.20 (GND), U6.21 (DIE_ATTACH); also elsewhere on the board
unnamed: C23.1, R32.1
unnamed: C25.1, U6.15 (Vref)

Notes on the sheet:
"Snubber network": NC?
No load current for GR42x25: 6.5A

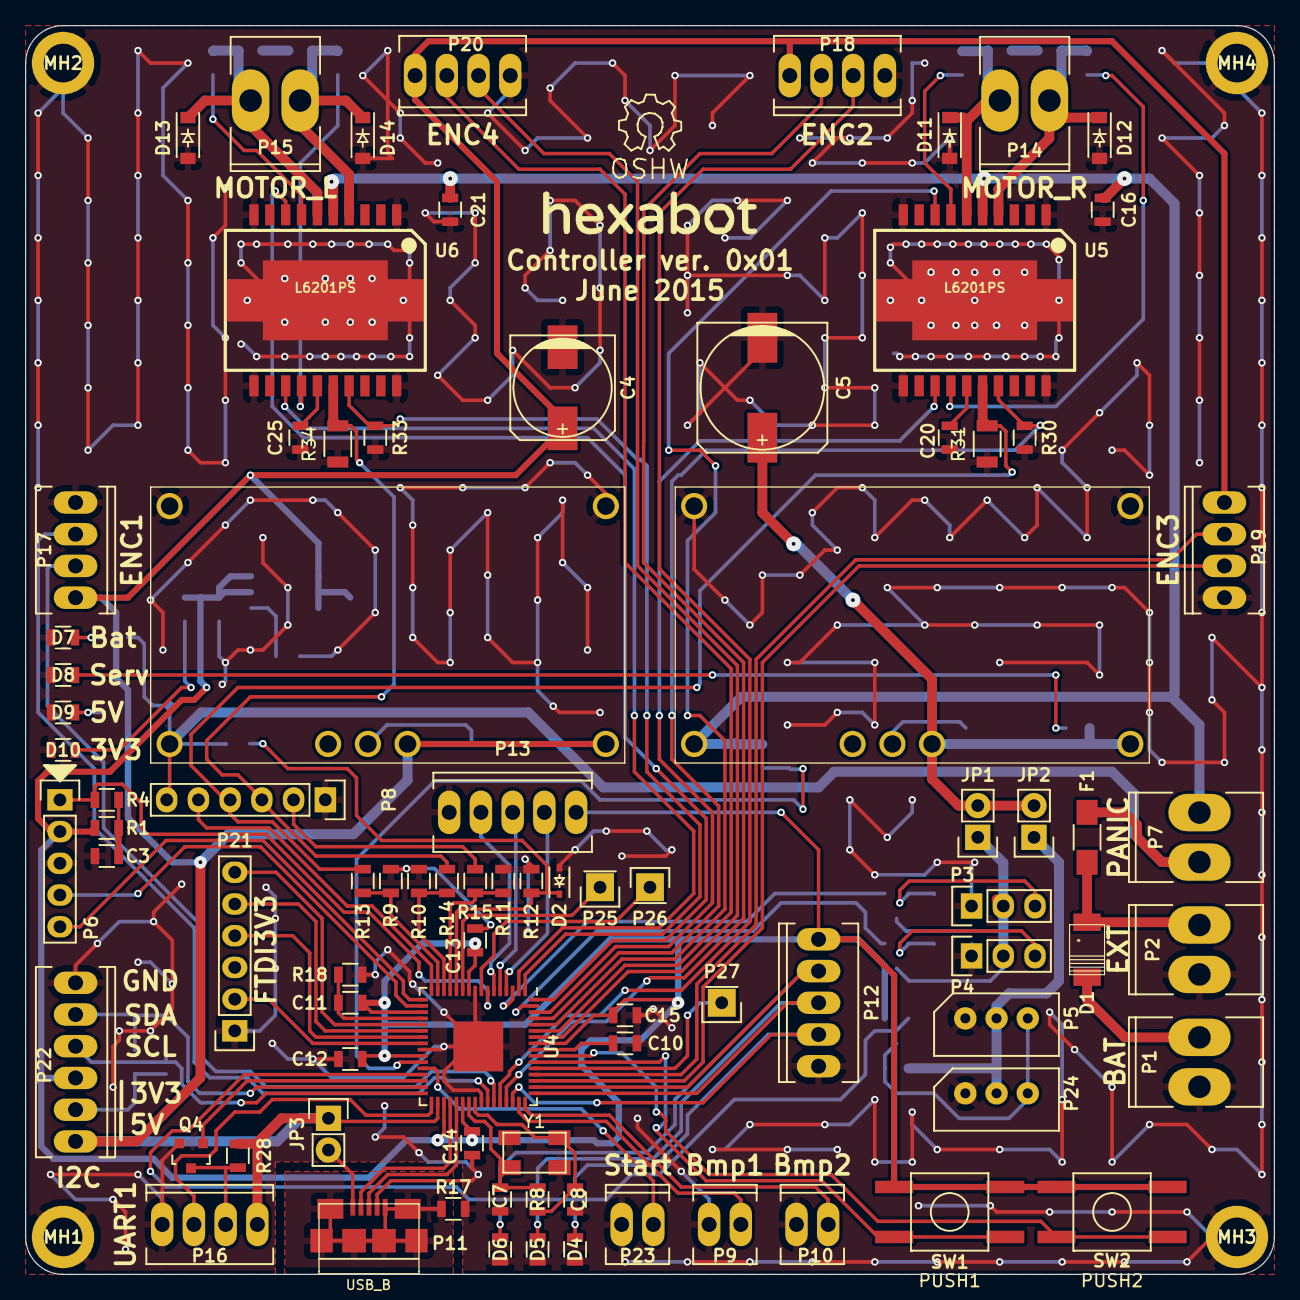
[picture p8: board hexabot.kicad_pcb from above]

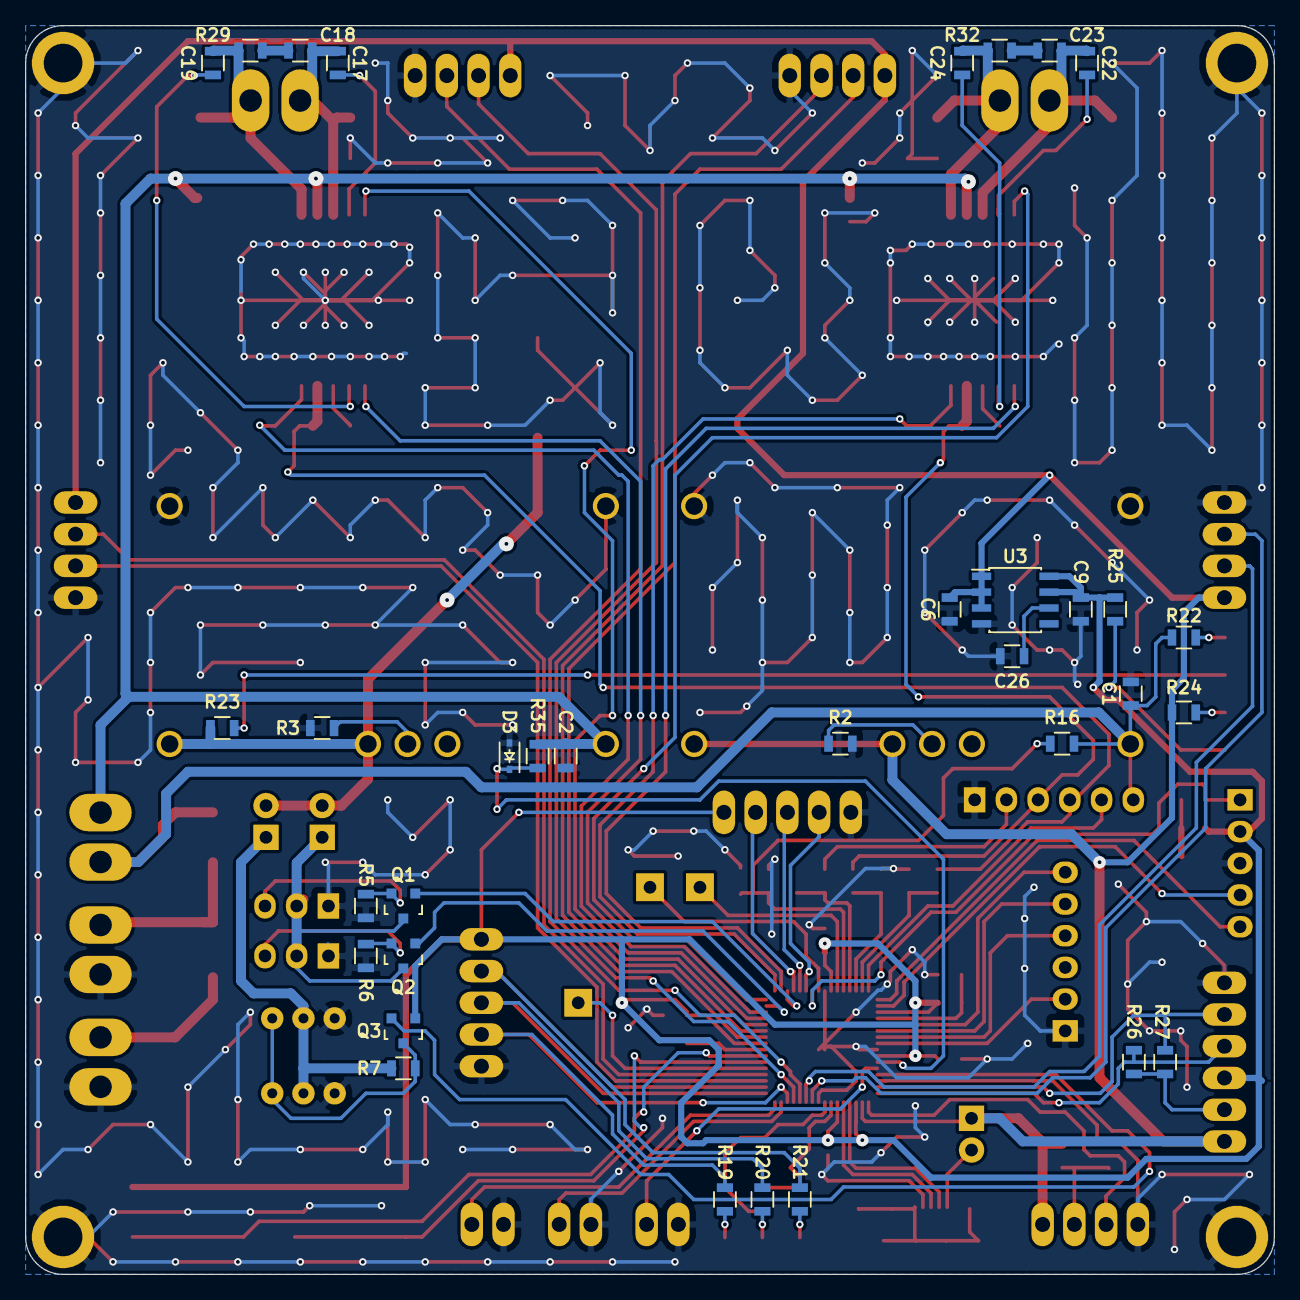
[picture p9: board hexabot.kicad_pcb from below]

Board: 2 copper layers, 100.0 x 100.0 mm, 124 parts (34 on the bottom side), 97 nets.

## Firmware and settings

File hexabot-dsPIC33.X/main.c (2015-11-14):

/********************************************************************
 Software License Agreement:

 The software supplied herewith by Microchip Technology Incorporated
 (the "Company") for its PIC(R) Microcontroller is intended and
 supplied to you, the Company's customer, for use solely and
 exclusively on Microchip PIC Microcontroller products. The
 software is owned by the Company and/or its supplier, and is
 protected under applicable copyright laws. All rights are reserved.
 Any use in violation of the foregoing restrictions may subject the
 user to criminal sanctions under applicable laws, as well as to
 civil liability for the breach of the terms and conditions of this
 license.

 THIS SOFTWARE IS PROVIDED IN AN "AS IS" CONDITION. NO WARRANTIES,
 WHETHER EXPRESS, IMPLIED OR STATUTORY, INCLUDING, BUT NOT LIMITED
 TO, IMPLIED WARRANTIES OF MERCHANTABILITY AND FITNESS FOR A
 PARTICULAR PURPOSE APPLY TO THIS SOFTWARE. THE COMPANY SHALL NOT,
 IN ANY CIRCUMSTANCES, BE LIABLE FOR SPECIAL, INCIDENTAL OR
 CONSEQUENTIAL DAMAGES, FOR ANY REASON WHATSOEVER.
 *******************************************************************/

/** INCLUDES *******************************************************/
#include <system.h>
#include <system_config.h>

#include <app.h>

#include <usb/usb.h>
#include <usb/usb_device.h>
#include <usb/usb_device_cdc.h>

/********************************************************************
 * Function:        void main(void)
 *
 * PreCondition:    None
 *
 * Input:           None
 *
 * Output:          None
 *
 * Side Effects:    None
 *
 * Overview:        Main program entry point.
 *
 * Note:            None
 *******************************************************************/
MAIN_RETURN main(void)
{
#if 0 // Blink test
    LED_Enable(LED_R);
    while(1) {
        unsigned int i;
        for (i = 0; i != 65535; i++) {
        }
        LED_Toggle(LED_R);
    }
#endif
    
    SYSTEM_Initialize(SYSTEM_STATE_USB_START);

    USBDeviceInit();
    USBDeviceAttach();
    
    
    while(1)
    {
        SYSTEM_Tasks();

        #if defined(USB_POLLING)
            // Interrupt or polling method.  If using polling, must call
            // this function periodically.  This function will take care
            // of processing and responding to SETUP transactions
            // (such as during the enumeration process when you first
            // plug in).  USB hosts require that USB devices should accept
            // and process SETUP packets in a timely fashion.  Therefore,
            // when using polling, this function should be called
            // regularly (such as once every 1.8ms or faster** [see
            // inline code comments in usb_device.c for explanation when
            // "or faster" applies])  In most cases, the USBDeviceTasks()
            // function does not take very long to execute (ex: <100
            // instruction cycles) before it returns.
            USBDeviceTasks();
        #endif


        /* If the USB device isn't configured yet, we can't really do anything
         * else since we don't have a host to talk to.  So jump back to the
         * top of the while loop. */
        if( USBGetDeviceState() < CONFIGURED_STATE )
        {
            /* Jump back to the top of the while loop. */
            continue;
        }

        /* If we are currently suspended, then we need to see if we need to
         * issue a remote wakeup.  In either case, we shouldn't process any
         * keyboard commands since we aren't currently communicating to the host
         * thus just continue back to the start of the while loop. */
        if( USBIsDeviceSuspended()== true )
        {
            /* Jump back to the top of the while loop. */
            continue;
        }

        //Application specific tasks
        APP_Tasks();

    }//end while
}//end main




bool USER_USB_CALLBACK_EVENT_HANDLER(USB_EVENT event, void *pdata, uint16_t size)
{
    switch( (int) event )
    {
        case EVENT_TRANSFER:
            break;

        case EVENT_SOF:
            /* We could use the SOF as a timer. */
            APP_UpdateUSBStatus(true);
            break;

        case EVENT_SUSPEND:
            APP_UpdateUSBStatus(false);
            break;

        case EVENT_RESUME:
            APP_UpdateUSBStatus(true);
            break;

        case EVENT_CONFIGURED:
            /* When the device is configured, we can (re)initialize the 
             * demo code. */
            APP_Initialize();
            break;

        case EVENT_SET_DESCRIPTOR:
            break;

        case EVENT_EP0_REQUEST:
            /* We have received a non-standard USB request.  The HID driver
             * needs to check to see if the request was for it. */
            USBCheckCDCRequest();
            break;

        case EVENT_BUS_ERROR:
            APP_UpdateUSBStatus(false);
            break;

        case EVENT_TRANSFER_TERMINATED:
            USBCDCEventHandler(event, pdata, size); // Useless?
            //CommandEventHandler(event, pdata, size);
            //...
            break;

        default:
            break;
    }
    return true;
}

/*******************************************************************************
 End of File
*/

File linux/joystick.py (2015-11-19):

#!/usr/bin/env python3
# https://gist.github.com/rdb/8864666

# Released by rdb under the Unlicense (unlicense.org)
# Based on information from:
# https://www.kernel.org/doc/Documentation/input/joystick-api.txt

import sys
import os, struct, array
from fcntl import ioctl

# Iterate over the joystick devices.
print('Available devices:')

for fn in os.listdir('/dev/input'):
    if fn.startswith('js'):
        print('  /dev/input/%s' % (fn))

# We'll store the states here.
axis_states = {}
button_states = {}

# These constants were borrowed from linux/input.h
axis_names = {
    0x00 : 'x',
    0x01 : 'y',
    0x02 : 'z',
    0x03 : 'rx',
    0x04 : 'ry',
    0x05 : 'rz',
    0x06 : 'trottle',
    0x07 : 'rudder',
    0x08 : 'wheel',
    0x09 : 'gas',
    0x0a : 'brake',
    0x10 : 'hat0x',
    0x11 : 'hat0y',
    0x12 : 'hat1x',
    0x13 : 'hat1y',
    0x14 : 'hat2x',
    0x15 : 'hat2y',
    0x16 : 'hat3x',
    0x17 : 'hat3y',
    0x18 : 'pressure',
    0x19 : 'distance',
    0x1a : 'tilt_x',
    0x1b : 'tilt_y',
    0x1c : 'tool_width',
    0x20 : 'volume',
    0x28 : 'misc',
}

button_names = {
    0x120 : 'trigger',
    0x121 : 'thumb',
    0x122 : 'thumb2',
    0x123 : 'top',
    0x124 : 'top2',
    0x125 : 'pinkie',
    0x126 : 'base',
    0x127 : 'base2',
    0x128 : 'base3',
    0x129 : 'base4',
    0x12a : 'base5',
    0x12b : 'base6',
    0x12f : 'dead',
    0x130 : 'a',
    0x131 : 'b',
    0x132 : 'c',
    0x133 : 'x',
    0x134 : 'y',
    0x135 : 'z',
    0x136 : 'tl',
    0x137 : 'tr',
    0x138 : 'tl2',
    0x139 : 'tr2',
    0x13a : 'select',
    0x13b : 'start',
    0x13c : 'mode',
    0x13d : 'thumbl',
    0x13e : 'thumbr',

    0x220 : 'dpad_up',
    0x221 : 'dpad_down',
    0x222 : 'dpad_left',
    0x223 : 'dpad_right',

    # XBox 360 controller uses these codes.
    0x2c0 : 'dpad_left',
    0x2c1 : 'dpad_right',
    0x2c2 : 'dpad_up',
    0x2c3 : 'dpad_down',
}

axis_map = []
button_map = []

# Open the joystick device.
fn = '/dev/input/js0'
print('Opening %s...' % fn)
jsdev = open(fn, 'rb')

# Get the device name.
buf = bytearray(63)
ioctl(jsdev, 0x80006a13 + (0x10000 * len(buf)), buf) # JSIOCGNAME(len)
print(buf.decode('utf8'))

# Get number of axes and buttons.
buf = array.array('B', [0])
ioctl(jsdev, 0x80016a11, buf) # JSIOCGAXES
num_axes = buf[0]

buf = array.array('B', [0])
ioctl(jsdev, 0x80016a12, buf) # JSIOCGBUTTONS
num_buttons = buf[0]

# Get the axis map.
buf = array.array('B', [0] * 0x40)
ioctl(jsdev, 0x80406a32, buf) # JSIOCGAXMAP

for axis in buf[:num_axes]:
    axis_name = axis_names.get(axis, 'unknown(0x%02x)' % axis)
    axis_map.append(axis_name)
    axis_states[axis_name] = 0.0

# Get the button map.
buf = array.array('H', [0] * 200)
ioctl(jsdev, 0x80406a34, buf) # JSIOCGBTNMAP

for btn in buf[:num_buttons]:
    btn_name = button_names.get(btn, 'unknown(0x%03x)' % btn)
    button_map.append(btn_name)
    button_states[btn_name] = 0

print('%d axes found: %s' % (num_axes, ', '.join(axis_map)))
print('%d buttons found: %s' % (num_buttons, ', '.join(button_map)))

def preview_loop():
    # Main event loop
    while True:
        evbuf = jsdev.read(8)
        if evbuf:
            time, value, type, number = struct.unpack('IhBB', evbuf)

            if type & 0x80:
                 print("(initial)", end="")

            if type & 0x01:
                button = button_map[number]
                if button:
                    button_states[button] = value
                    if value:
                        print("%s pressed" % (button))
                    else:
                        print("%s released" % (button))

            if type & 0x02:
                axis = axis_map[number]
                if axis:
                    fvalue = value / 32767.0
                    axis_states[axis] = fvalue
                    print("%s: %.3f" % (axis, fvalue))

import time
import threading
left_speed = 0.0
right_speed = 0.0
command_pending = True
def control_loop():
    global dev, command_pending, right_speed, left_speed # TODO class
    
    fw_speed = 0
    rot_speed = 0

    while True:
        evbuf = jsdev.read(8)
        if evbuf:
            t, value, type, number = struct.unpack('IhBB', evbuf)

            if type & 0x80:
                 print("(initial)", end="")

            if type & 0x01:
                button = button_map[number]
                if button:
                    button_states[button] = value
                    if value:
                        print("%s pressed" % (button))
                    else:
                        print("%s released" % (button))

            if type & 0x02:
                axis = axis_map[number]
                if axis:
                    fvalue = value / 32767.0
                    axis_states[axis] = fvalue
                    print("%s: %.3f" % (axis, fvalue))
                    
                    if axis == 'x':
                        rot_speed = -fvalue
                    elif axis == 'y':
                        fw_speed = -fvalue
                    else:
                        continue
                    
                    right = fw_speed + rot_speed
                    left  = fw_speed - rot_speed
                    
                    speed_limiter = max(1.0, left, right, -left, -right)
                    right_speed = right / speed_limiter
                    left_speed  = left / speed_limiter
                    
                    command_pending = True

def command_loop(): # Throttle when the joystick sends too many events. FIXME: improve with events.
    global command_pending, dev
    while True:
        while not command_pending:
            time.sleep(.05)
        print("left=%s right=%s" % (left_speed, right_speed))

        command_pending = False
        for (reg, value) in [(38, right_speed), (39, left_speed)]:
            print("cmd=%s" % [reg, value])
            dev.send_command([reg, value])
            answer = dev.receive_command()
            #~ print(' '.join([format(i, '02x') for i in answer]))


if __name__ == '__main__':
    if 'preview' in sys.argv:
        preview_loop()
    else:
        import usb_controller
        dev = usb_controller.USBController([usb_controller.COMMAND_INTERFACE])

        thread = threading.Thread(target=control_loop)
        thread.setDaemon(True)
        thread.start()
    
        command_loop() # Crash main thread on USB error.

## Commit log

2015-06-06 Add layout and schematics, update README, change iso
    [hexabot-B_Cu.gbl, hexabot-B_Mask.gbs, hexabot-B_Paste.gbp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]
2015-06-07 Create project and schematic for dsPIC
    [hexabot.sch]
2015-06-07 Cleanup paths
    [hexabot.kicad_pcb, hexabot.sch]
2015-06-09 Start schematic
    [hexabot.sch]
2015-06-09 More sch
    [hexabot.sch]
2015-06-10 Subsheet for drivers
    [driver.sch, hexabot.sch]
2015-06-10 PIC datasheet added Footprint library created
2015-06-10 Most of sch ready
    [driver.sch, hexabot.sch]
2015-06-11 Probably ready for layout
    [driver.sch, hexabot.sch]
2015-06-11 Partial footprint association
    [driver.sch, hexabot.kicad_pcb, hexabot.sch]
2015-06-11 Remove KK for motors
    [driver.sch, hexabot.sch]
2015-06-13 Add footprint for AX-12 connector
2015-06-13 First draft layout. To optimize to 10*10cm
2015-06-14 Draft layout with files
    [driver.sch, hexabot.kicad_pcb, hexabot.sch]
2015-06-14 Add new crystal footprint
2015-06-14 Layout nearly done, ground plane to check, missing connections, change quartz footprint
    [driver.sch, hexabot.kicad_pcb, hexabot.sch]
2015-06-15 Layout done, check to do, logo to add
    [hexabot.kicad_pcb]
2015-06-15 Layout done. Print test to do.
    [driver.sch, hexabot.kicad_pcb, hexabot.sch]
2015-06-22 Few modifs on silk screen gerber generated
    [hexabot-B_Cu.gbl, hexabot-B_Mask.gbs, hexabot-B_Paste.gbp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]
2015-06-23 Rsense footprintf modified. Anular ring adjusted. Ready to order
    [driver.sch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]
2015-06-27 SeeedFusionPCB order files v1
    [hexabot-B_Cu.gbl, hexabot-B_Mask.gbs, hexabot-B_Paste.gbp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]
2015-06-27 Move previous files to kicad/, add CDC demo for dspic33E in a single dir
    [driver.sch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]
2015-07-06 Add timer
2015-07-11 Add some 3D packages
    [hexabot.kicad_pcb, hexabot.sch]
2015-07-15 Blinking the board works. Approx 1 Hz with FRC.
2015-07-16 Add BOM for v1
    [hexabot.csv]
2015-07-22 Fix silkscreen ENC3 => ENC4
    [hexabot.kicad_pcb]
2015-07-22 Servo and ENC1-4 work, remove some debug code
2015-07-22 Fix servo transistor in schematics, the netlist will have to change
    [hexabot.sch]
2015-07-22 Inverse polarity of output-compare following the servo rework
    [app_registers.c, system.c]
2015-07-22 Swap MOTOR_R_PWM and MOTOR_R_DIR1 because of RP80, the netlist will have to change
    [hexabot.sch]
2015-07-23 Control H bridge pins with PWM
2015-07-27 Add pullup/down, finish ADC config, fix metrics
    [app.c, hexabot.py, system.c]
2015-07-28 Cleanup, duplication, fix motors
    [app.c, app_registers.c, system.c]
2015-08-05 Add TODOs to improve VSENSE
    [hexabot.sch]
2015-11-08 Try to fix the inversion
    [app.c]
2015-11-08 Add float commands, float motor control that works, basic speed sensing
2015-11-08 Basic PI controller on both motors
2015-11-09 Software QEI seems to work (few errors), but would benefit from rigorous testing.
    [app_registers.c, interrupts.c, system.c]
2015-11-09 Tested the different encoder combinations. TODO: use the HW QEI to validate the SW QEI.
2015-11-09 Untested odometry
2015-11-10 Basic odometry with html display
2015-11-11 Remove iter_unpack for python 3.2, throttle joystick events
2015-11-11 Updated README, cleaner svg ui, improve odometry, more outputs for commands
2015-11-14 Change app_led_usb_status, stop motors on USB disconnect
2015-11-14 Finally traced the CDC corruption back to XC16-781 bug
2015-11-14 Don't cut in the middle of dropped lines
2015-11-14 Convert joystick to python3, crash on disconnect, Ui server listens on all interfaces
    [joystick.py]
2015-11-14 Reduce PWM noise, simpler speed decoding, clean dependencies
    [app.c, app_registers.c, system.c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]
2015-11-19 WIP: Try to implement polar control with external encoder feedback. More work is needed.
